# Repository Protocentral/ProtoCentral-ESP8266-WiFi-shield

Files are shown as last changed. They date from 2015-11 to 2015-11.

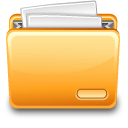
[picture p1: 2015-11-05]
Firmware/nodemcu-flasher-master/Resources/Images/File.png

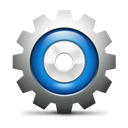
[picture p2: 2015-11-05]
Firmware/nodemcu-flasher-master/Resources/Images/Setting.png

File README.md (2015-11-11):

ProtoCentral ESP8266 WiFi shield 
==================================
 [ESP8266Shield  
*ProtoCentral ESP8266 WiFi shield (PC-4356)*](https://www.protocentral.com/arduino-shields/944-protocentral-esp8266-wifi-shieldstandalone-for-arduino.html)
 
The ESP8266 WiFi chip has taken the IoT world by storm by breaking the cost barrier and making the IoT truly possible. The ProtoCentral ESP8266 WiFi shield is an easy and quick way to add WiFi functionality to your Arduino.
This board can be used an Arduino shield as well as a standalone breakout board if you prefer to program the ESP8266 directly. The onboard FT230X USB-to-UART circuit allows direct access to to the ESP 8266 module's UART interface. This allows programming of the ESP8266 chip's onboard processor to run the application itself without the need for an Arduino.
The module comes pre-flashed with the ESP8266 AT command set firmware. 

Features Overload!
-------------------
*	Slide switch - Serial communication support to work on ESP module individually
*	Firmware upgrade for ESP through USB
*	On board FTDI
*	Onboard regulator 3.3v with 800mA
*	Can be powered on/off using USB or from the Arduino board 
*	Board is pre-flashed  with an AT command set firmware and the same can be used to control ESP8266 module
*	Extra ESP8266 pins broken out for any additional usage requirements
*	802.11 b/g/n
*	Wi-Fi Direct (P2P), soft-AP
*	Integrated TCP/IP protocol stack

Includes:
----------
* Shield with the headers

Repository Contents
-------------------
* **/Firmware**  - Firmware and bin files for ESP8266
* **/Libraries** - Arduino library and example sketches.
* **/Hardware**  - All Eagle design files (.brd, .sch)

License Information
-------------------
This product is open source!

Please use, reuse, and modify these files as you see fit. Please maintain attribution to Protocentral and release anything derivative under the same license.

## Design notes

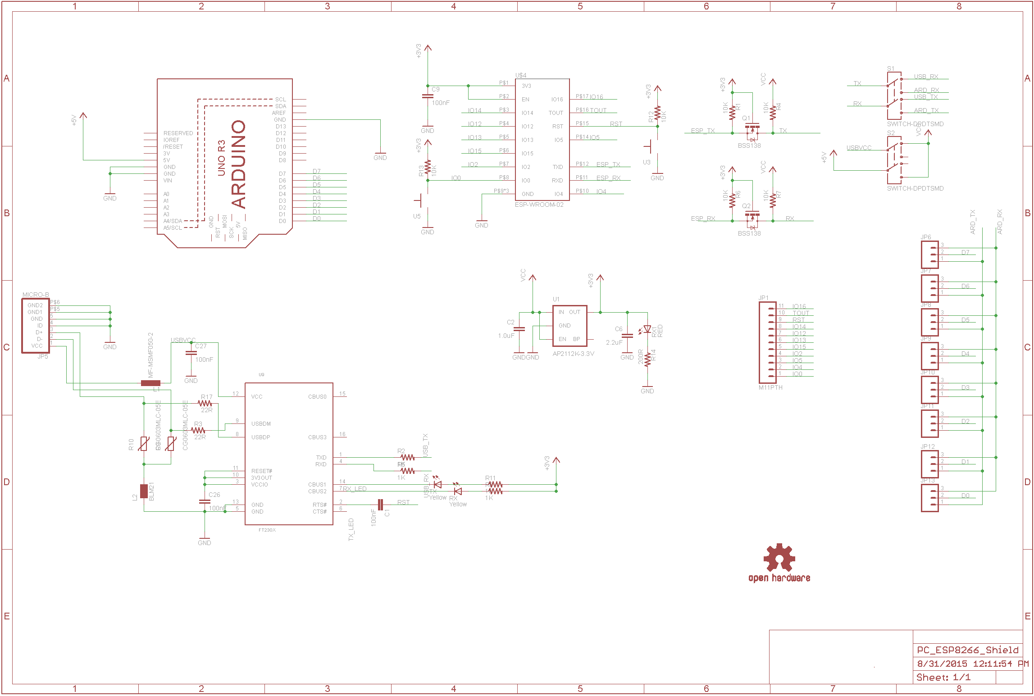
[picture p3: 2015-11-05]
Hardware/ProtoCentral_ESP8266_Shield/ESP8266Shield.png

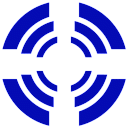
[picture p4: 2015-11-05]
Firmware/nodemcu-flasher-master/Resources/Images/Wait.GIF

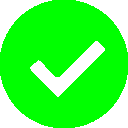
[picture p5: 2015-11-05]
Firmware/nodemcu-flasher-master/Resources/Images/Yes.png

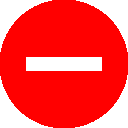
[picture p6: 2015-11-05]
Firmware/nodemcu-flasher-master/Resources/Images/No.png

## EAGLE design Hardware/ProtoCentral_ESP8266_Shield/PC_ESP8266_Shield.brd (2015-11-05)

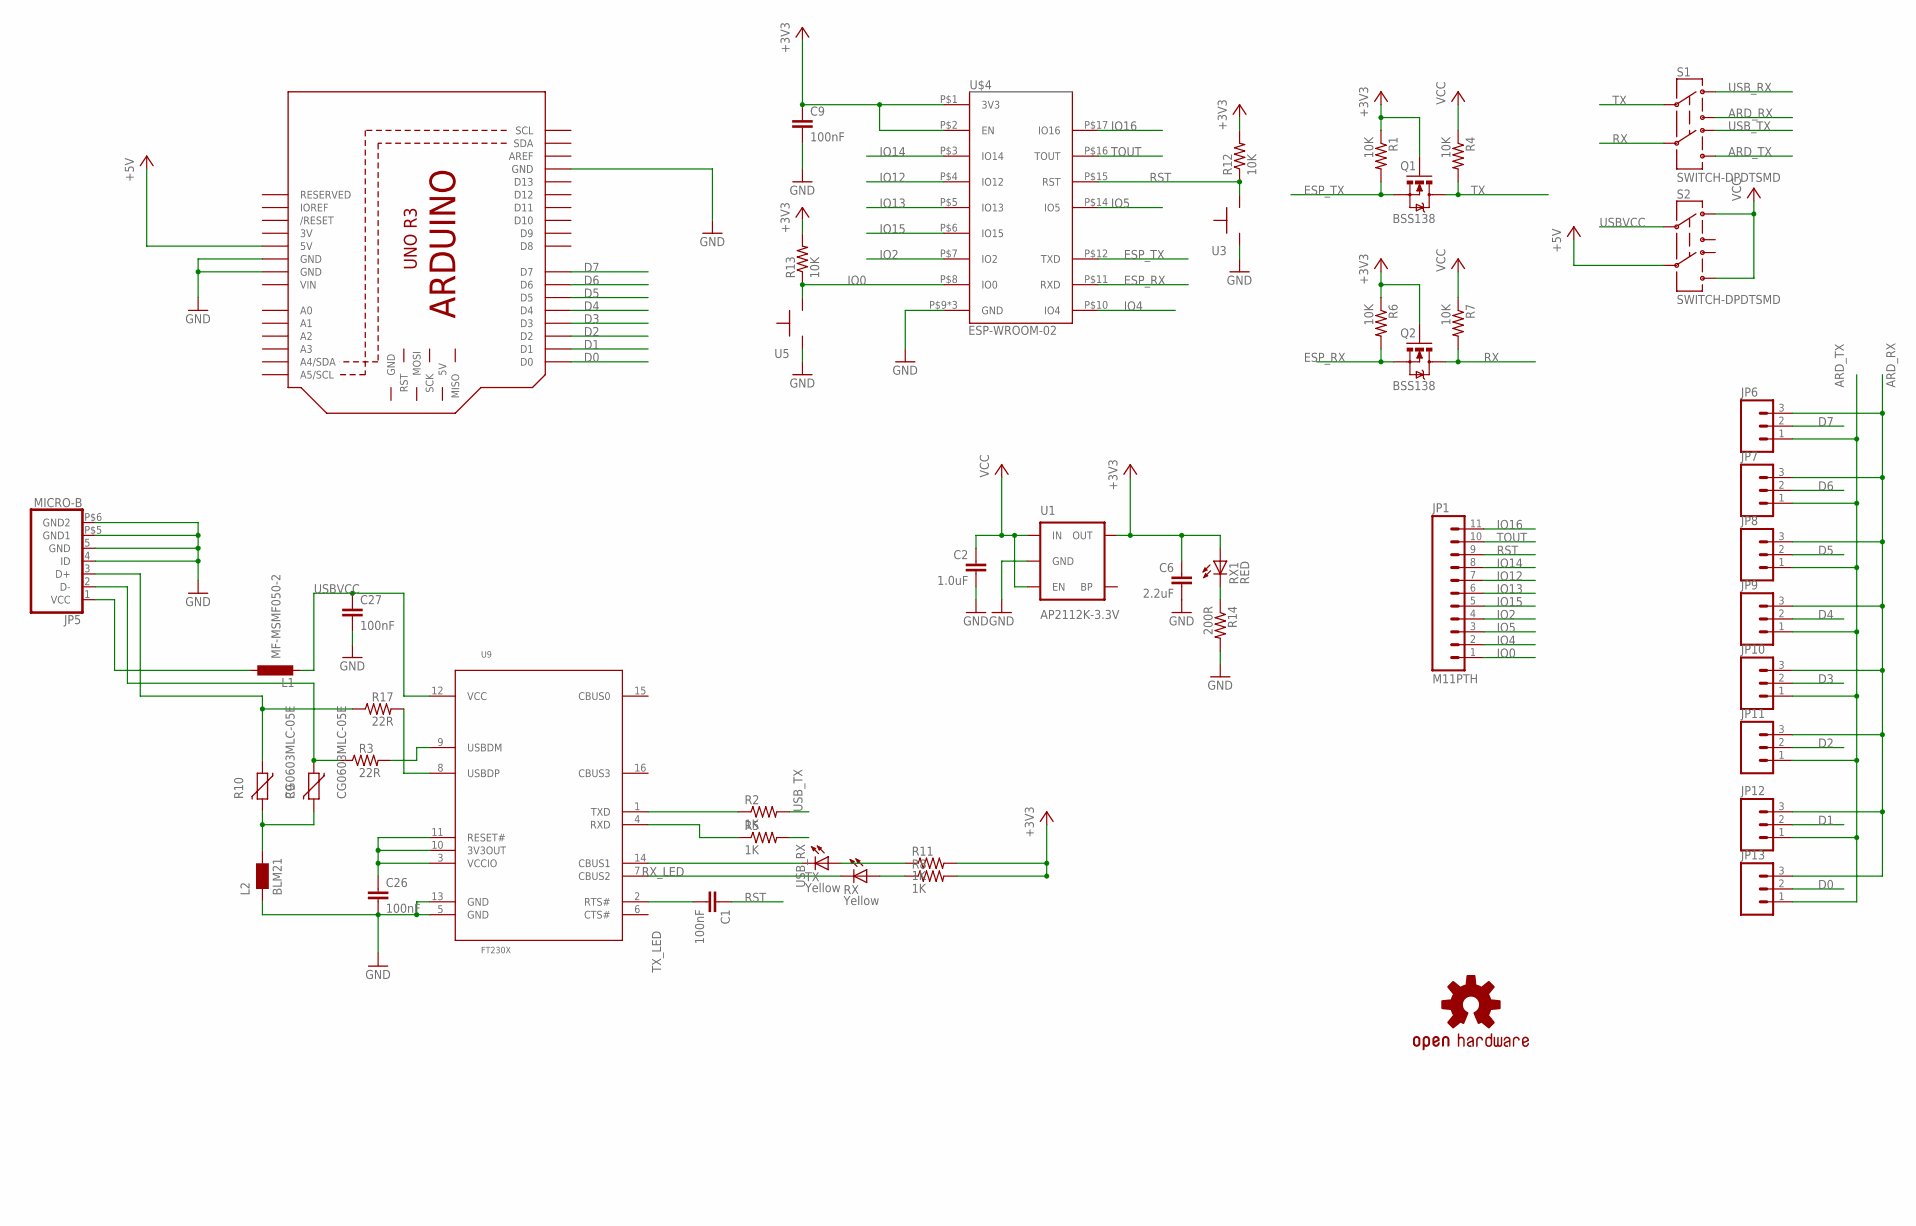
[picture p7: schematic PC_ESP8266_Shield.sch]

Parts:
C1, C9, C26, C27: 100nF; C0805
C2: 1.0uF; 0805
C6: 2.2uF; C0805
JP1: M11PTH; 1X11
JP5: MICRO-B
JP6, JP7, JP8, JP9, JP10, JP11, JP12, JP13: M03PTH; 1X03
L1: MF-MSMF050-2; L1812
L2: BLM21; 0805
Q1, Q2: BSS138; SOT23-3
R1, R4, R6, R7, R12, R13: 10K; R0805
R2, R5, R8, R11: 1K; R0805
R3, R17: 22R; R0805
R9, R10: CG0603MLC-05E; CT/CN0603
R14: 200R; R0805
RX: Yellow; CHIPLED_0603
RX1: RED; CHIPLED_0603
S1, S2: SWITCH-DPDTSMD; AYZ0202
TX: Yellow; CHIPLED_0603
U1: AP2112K-3.3V; SOT23-5
U3, U5: B3U-1000P
U9: FT230X; SSOP_16
U$1: ARDUINO
U$3: PROTY-LOGO; LOGO-PROTY
U$4: ESP-WROOM-02
U$5: OSHW-LOGOS; OSHW-LOGO-S

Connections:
3V: U$1.3V
+3V3: C6.1, C9.1, Q1.1 (G), Q2.1 (G), R1.1, R6.1, R8.2, R11.2, R12.2, R13.2, RX1.A, U1.5 (OUT), U$4.P$1 (3V3), U$4.P$2 (EN)
+5V: S2.5, U$1.5V
ARD_RX: JP6.3, JP7.3, JP8.3, JP9.3, JP10.3, JP11.3, JP12.3, JP13.3, S1.3
ARD_TX: JP6.1, JP7.1, JP8.1, JP9.1, JP10.1, JP11.1, JP12.1, JP13.1, S1.6
D0: JP13.2, U$1.D0
D1: JP12.2, U$1.D1
D2: JP11.2, U$1.D2
D3: JP10.2, U$1.D3
D4: JP9.2, U$1.D4
D5: JP8.2, U$1.D5
D6: JP7.2, U$1.D6
D7: JP6.2, U$1.D7
ESP_RX: Q2.2 (S), R6.2, U$4.P$11 (RXD)
ESP_TX: Q1.2 (S), R1.2, U$4.P$12 (TXD)
GND: C2.2, C6.2, C9.2, C26.2, C27.2, JP5.4 (ID), JP5.5 (GND), JP5.P$5 (GND1), JP5.P$6 (GND2), L2.1, R14.2, U1.2 (GND), U3.P$1, U5.P$1, U9.5 (GND), U9.13 (GND), U$1.GND, U$1.GND@1 (GND), U$1.GND@2 (GND), U$4.P$9 (GND), U$4.P$13 (GND), U$4.P$18 (GND)
IO0: JP1.1, R13.1, U5.P$2, U$4.P$8 (IO0)
IO2: JP1.4, U$4.P$7 (IO2)
IO4: JP1.2, U$4.P$10 (IO4)
IO5: JP1.3, U$4.P$14 (IO5)
IO12: JP1.7, U$4.P$4 (IO12)
IO13: JP1.6, U$4.P$5 (IO13)
IO14: JP1.8, U$4.P$3 (IO14)
IO15: JP1.5, U$4.P$6 (IO15)
IO16: JP1.11, U$4.P$17 (IO16)
unnamed: R2.1, U9.1 (TXD)
unnamed: C1.2, U9.2 (RTS#)
unnamed: R5.1, U9.4 (RXD)
unnamed: R8.1, RX.A
unnamed: R11.1, TX.A
unnamed: JP5.1 (VCC), L1.1
unnamed: R14.1, RX1.C
unnamed: R3.2, U9.9 (USBDM)
unnamed: C26.1, U9.3 (VCCIO), U9.10 (3V3OUT), U9.11 (RESET#)
unnamed: JP5.2 (D-), R3.1, R9.1
unnamed: R17.2, U9.8 (USBDP)
unnamed: L2.2, R9.2, R10.2
unnamed: JP5.3 (D+), R10.1, R17.1
RST: C1.1, JP1.9, R12.1, U3.P$2, U$4.P$15 (RST)
RX: Q2.3 (D), R7.2, S1.5
RX_LED: RX.C, U9.7 (CBUS2)
TOUT: JP1.10, U$4.P$16 (TOUT)
TX: Q1.3 (D), R4.2, S1.2
TX_LED: TX.C, U9.14 (CBUS1)
USBVCC: C27.1, L1.2, S2.2, U9.12 (VCC)
USB_RX: R5.2, S1.1
USB_TX: R2.2, S1.4
VCC: C2.1, R4.1, R7.1, S2.1, S2.6, U1.1 (IN), U1.3 (EN)
VIN: U$1.VIN

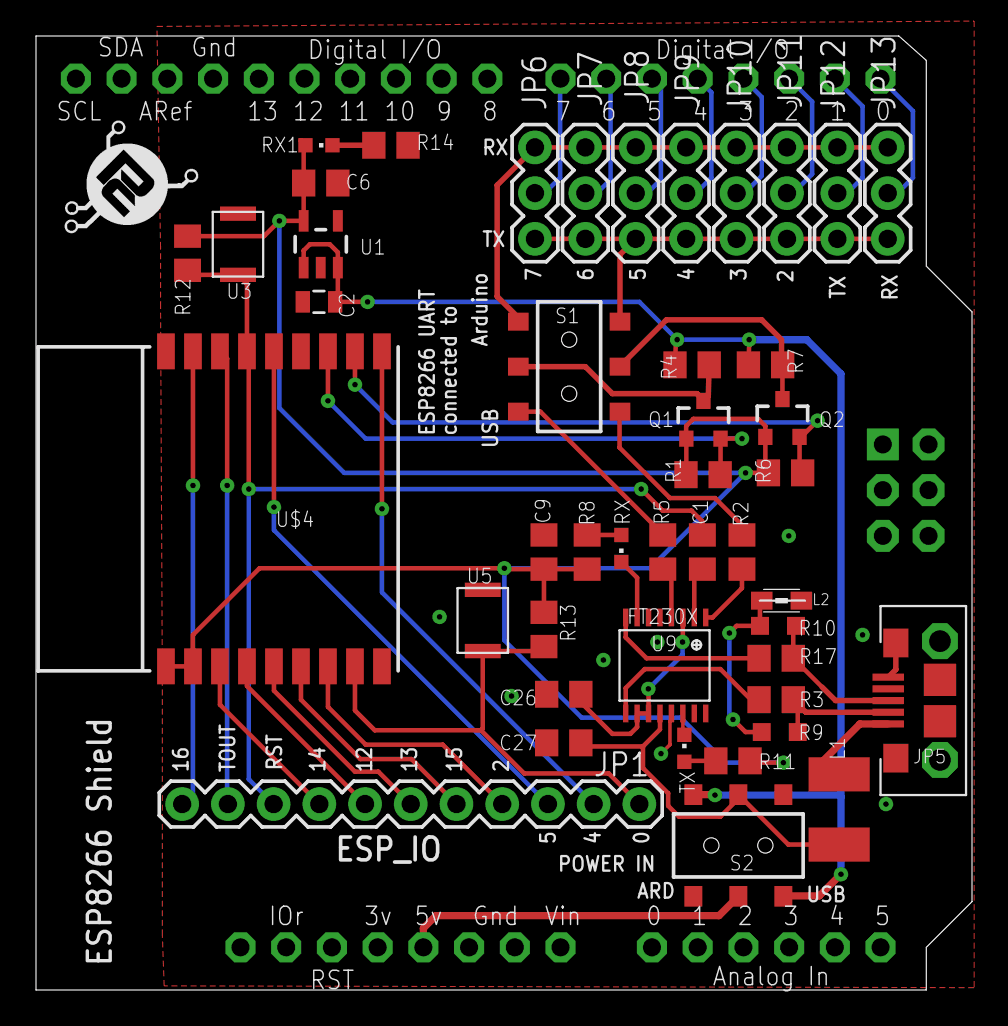
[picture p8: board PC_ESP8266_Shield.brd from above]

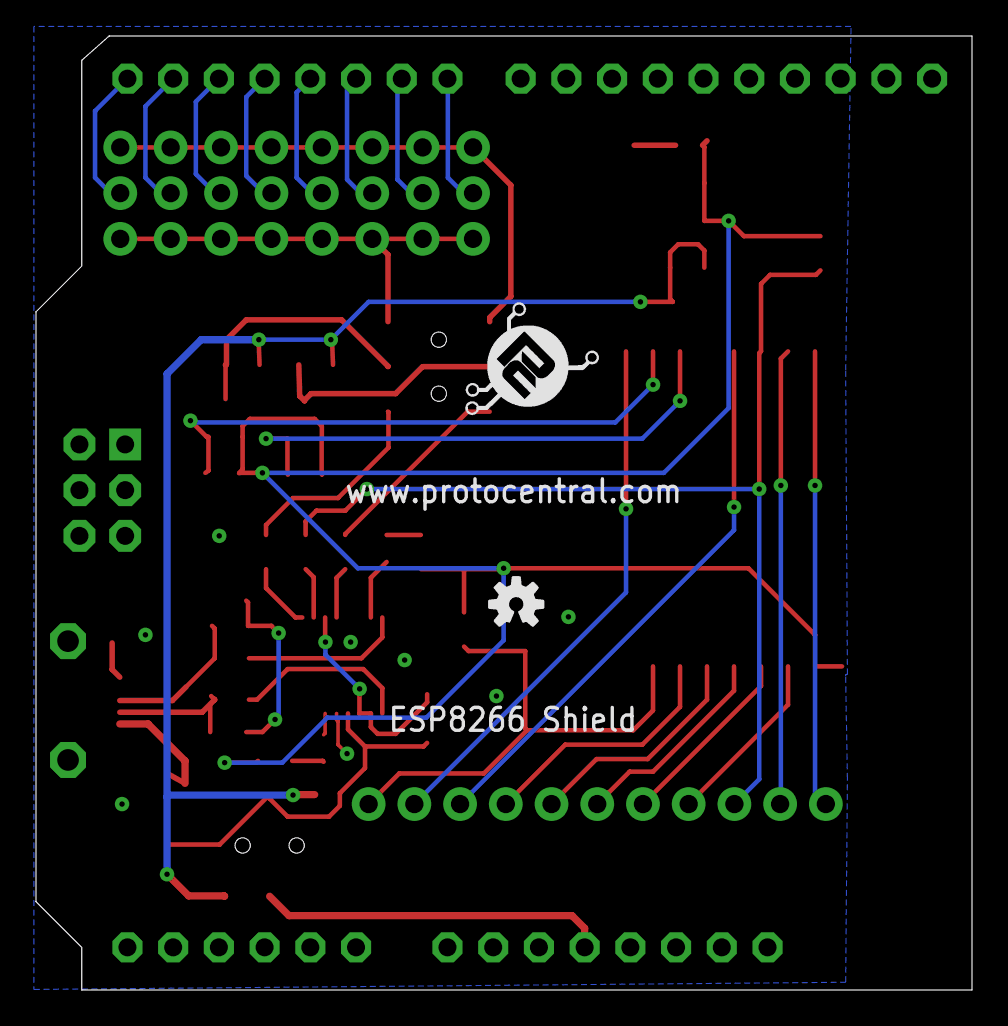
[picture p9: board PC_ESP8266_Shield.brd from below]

Board: 4 copper layers, 52.0 x 53.0 mm, 49 parts (2 on the bottom side), 47 nets.

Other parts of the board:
U$2: PROTY-LOGO; LOGO-PROTY

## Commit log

2015-11-05 Design File
    [PC_ESP8266_Shield.brd, PC_ESP8266_Shield.sch]
2015-11-05 Arduino source code and example sketches

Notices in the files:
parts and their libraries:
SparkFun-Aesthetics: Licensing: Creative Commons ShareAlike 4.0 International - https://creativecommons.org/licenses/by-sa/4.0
